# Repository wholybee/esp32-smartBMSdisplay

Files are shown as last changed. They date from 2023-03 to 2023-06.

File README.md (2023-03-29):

# esp32-smartBMSdisplay
ESP32 version of JBD BMS display with Bluetooth connection

This is a BMS monitor for JBD and Overkill Solar BMS. It supports bluetooth connection to the BMS, and can alarm prior to BMS disconnect per ABYC recommendation. It is inspired by a project at https://github.com/vagueDirector/ArduinoXiaoxiangSmartBMSDisplay, but bears little resemblance at this point.

This project uses the Overkill Solar library for accessing the BMS, and modifiyed code from https://github.com/avinabmalla/ESP32_BleSerial

I used an ESP32-WROOM. Others might work also. BLE enabled Arduinos will not work. The ESP32 will connect to the first BMS it finds via bluetooth. Button one cycles through screens, and button two silences the alarm if it is triggered.

To use the alarm requires some changes in the BMS programming. There is a parameter for the delay in seconds before the cutoff occurs. Normally this is set very small, to 1 or 2 seconds. This value is how long of a warning you will get before the cutoff occurs. Some versions of the app do not allow this to be set greater than 10 seconds, but using the Overkill Solar app allows higher values.

Care should be taken when selecting the delay value. If an overvoltage or undervoltage situation occurs, there should be no issue waiting 20 or 30 seconds. If an overcurrent situation occurs, you really should not wait to disconnect to allow for an alarm, regardless of what ABYC says. So, I suggest leaving the delay for overcurrent very low, and changing the delay for overvoltage to 20 or 30 seconds.

ESP32 WROOM - https://www.amazon.com/gp/product/B08MQDS6WV/ref=ppx_yo_dt_b_search_asin_title
128x64 OLED screen - https://www.amazon.com/gp/product/B08BRCBKNR/ref=ppx_yo_dt_b_asin_title_o01_s00
Button - https://www.digikey.com/en/products/detail/c-k/KSA0A531-LFTR/5975610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
Button cap - https://www.digikey.com/en/products/detail/c-k/BTNK0120/498768?s=N4IgTCBcDaICwAYCMBaJYDMBOFA5AIiALoC%2BQA
Buzzer - https://www.amazon.com/gp/product/B07TRK5M2T/ref=ppx_yo_dt_b_search_asin_title

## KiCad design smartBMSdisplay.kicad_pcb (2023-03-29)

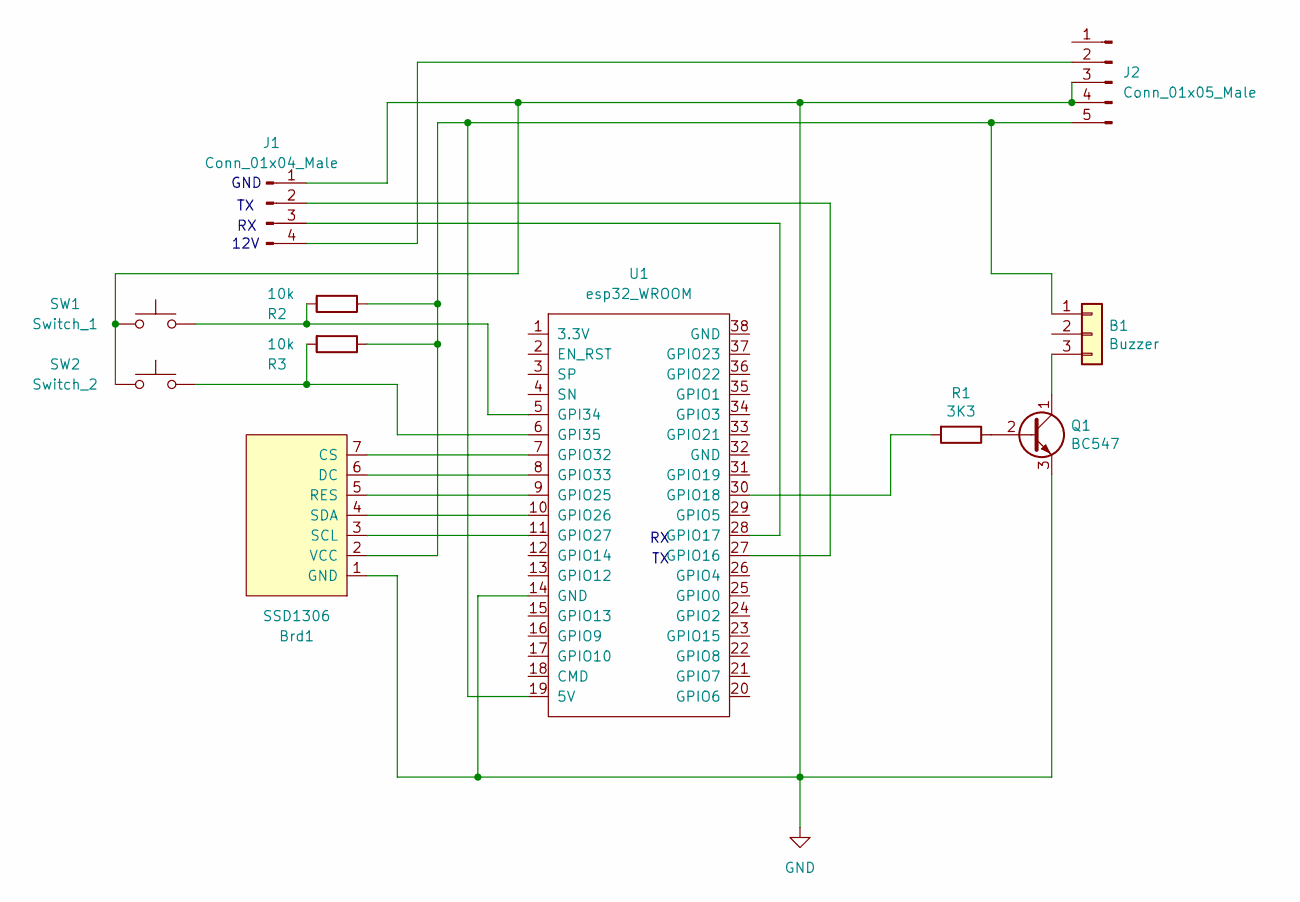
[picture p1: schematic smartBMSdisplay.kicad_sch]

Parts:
B1: Buzzer; PinHeader_1x03_P2.00mm_Vertical
Brd1: SSD1306; 128x64OLED
J1: Conn_01x04_Male; PinHeader_1x04_P2.54mm_Vertical
J2: Conn_01x05_Male; PinHeader_1x05_P2.54mm_Vertical
Q1: BC547; TO-92_HandSolder
R1: 3K3; R_Axial_DIN0207_L6.3mm_D2.5mm_P10.16mm_Horizontal
R2, R3: 10k; R_Axial_DIN0207_L6.3mm_D2.5mm_P10.16mm_Horizontal
SW1: Switch_1; SW_Tactile_Straight_KSA0Axx1LFTR
SW2: Switch_2; SW_Tactile_Straight_KSA0Axx1LFTR
U1: esp32_WROOM; ESP32_Devkit_38Pins

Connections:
GND: Brd1.1 (GND), J1.1, J2.3, J2.4, Q1.3 (E), SW1.2, SW2.2, U1.14 (GND)
unnamed: B1.1, Brd1.2 (VCC), J2.5, R2.1, R3.1, U1.19 (5V)
unnamed: B1.3, Q1.1 (C)
unnamed: Brd1.3 (SCL), U1.11 (GPIO27)
unnamed: Brd1.4 (SDA), U1.10 (GPIO26)
unnamed: Brd1.5 (RES), U1.9 (GPIO25)
unnamed: Brd1.6 (DC), U1.8 (GPIO33)
unnamed: Brd1.7 (CS), U1.7 (GPIO32)
unnamed: J1.2, U1.27 (GPIO16)
unnamed: J1.3, U1.28 (GPIO17)
unnamed: J1.4, J2.2
unnamed: Q1.2 (B), R1.1
unnamed: R1.2, U1.30 (GPIO18)
unnamed: R2.2, SW1.1, U1.5 (GPI34)
unnamed: R3.2, SW2.1, U1.6 (GPI35)

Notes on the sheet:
12V
GND

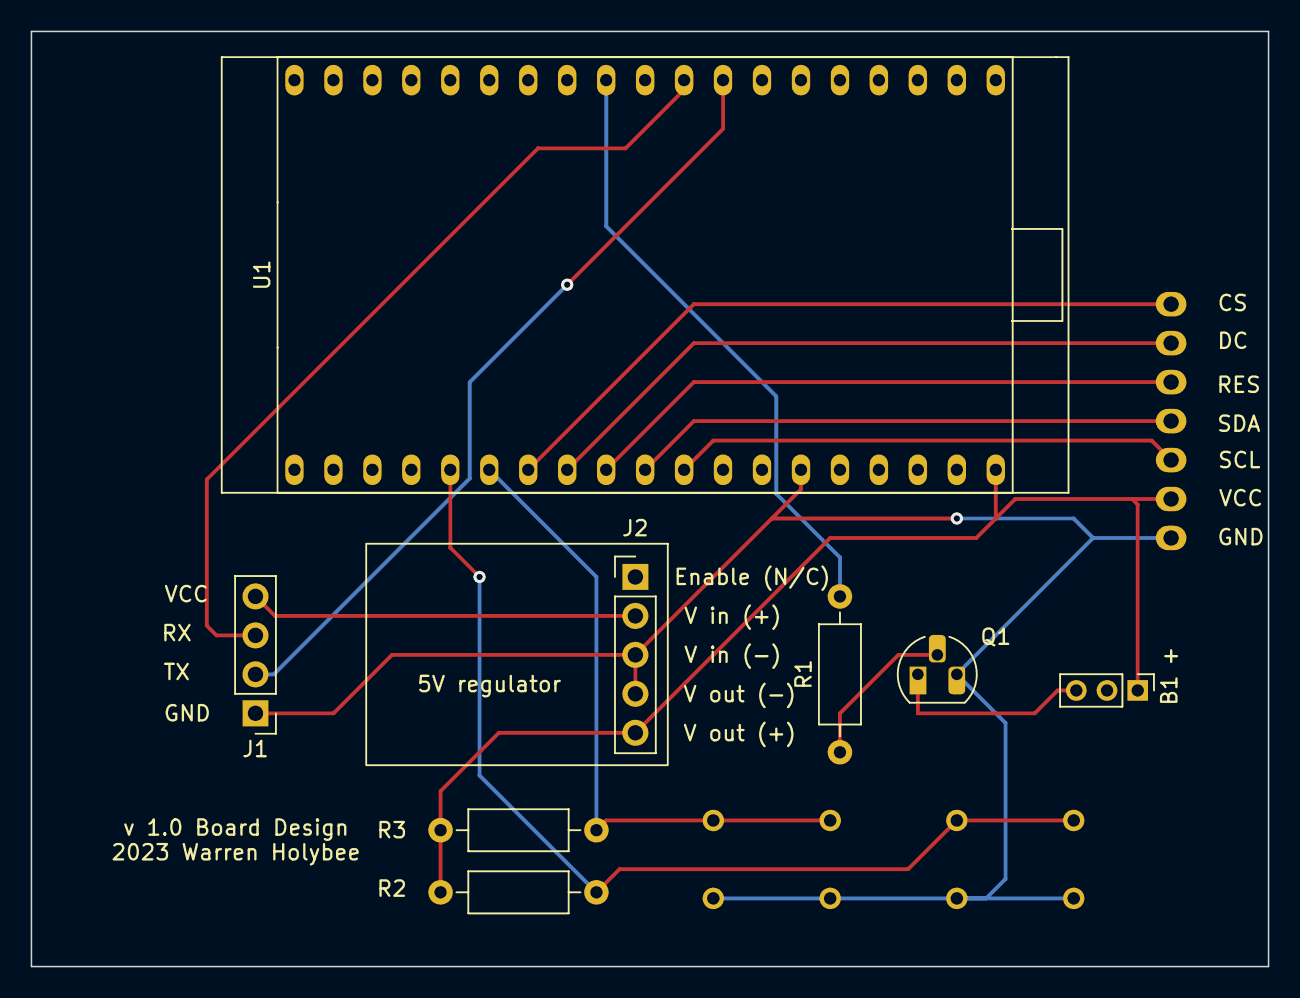
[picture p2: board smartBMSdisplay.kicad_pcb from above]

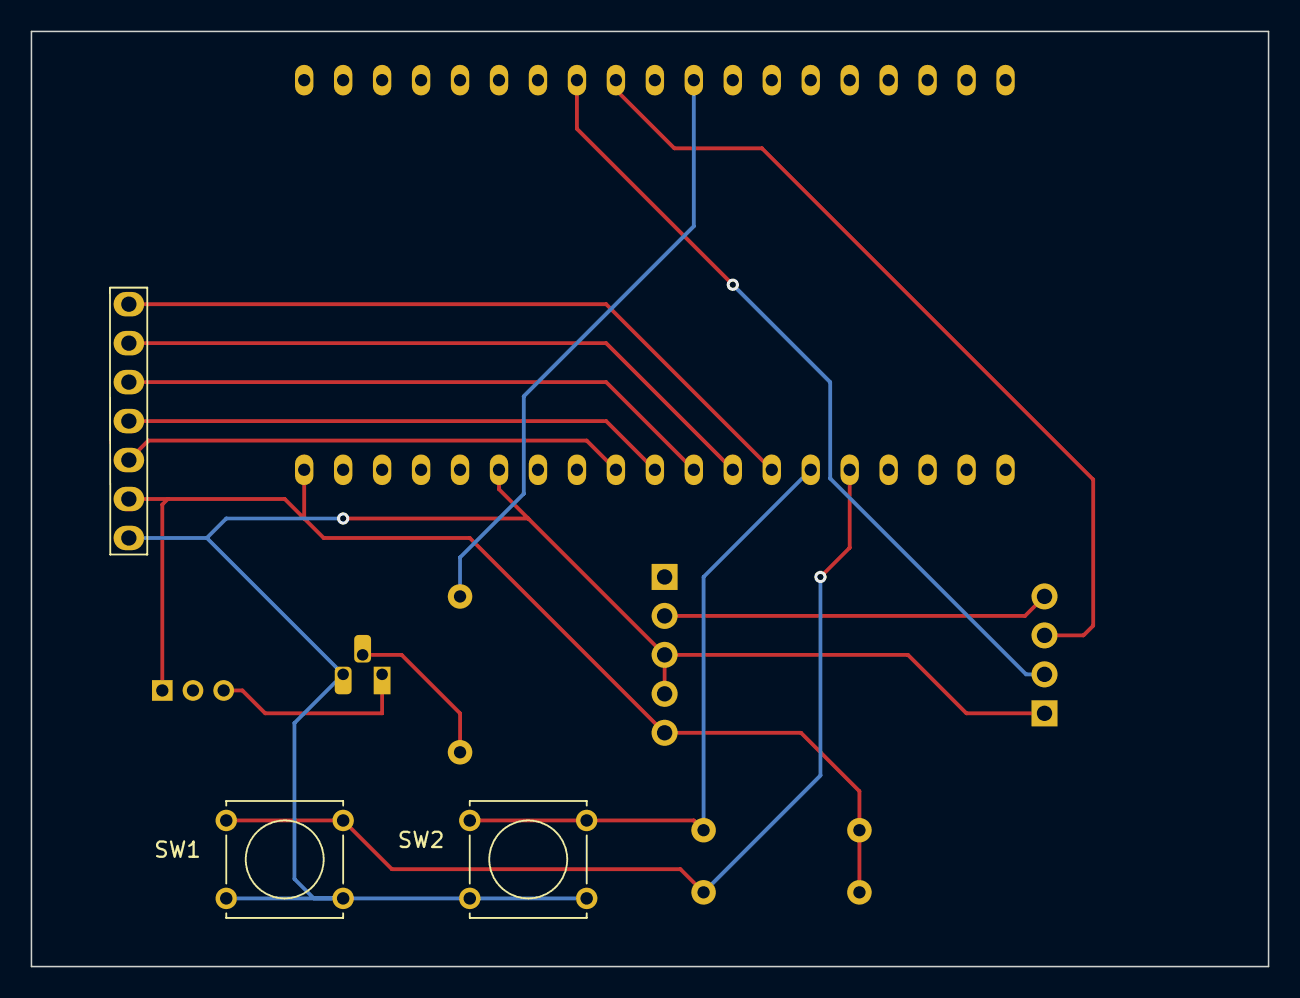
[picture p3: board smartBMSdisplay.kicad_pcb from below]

Board: 2 copper layers, 80.6 x 61.0 mm, 11 parts (3 on the bottom side), 15 nets.

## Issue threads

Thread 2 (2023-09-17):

is there a wiring diagram for your code please? I am looking at trying to read from two jbd BMS and display combined soc. information... thanks

CornishWoodsman, 2023-09-17:

wholybee, 2023-09-19:
The Kicad files include a schematic and PCB design files. This project can only talk to one BMS at a time.  To talk to 2 would be much easier with a wired connection instead of bluetooth.

CornishWoodsman, 2023-09-24:
My battery boxes are sealed and I have no access to the wired connection.
I have successfully read them consecutively from my linux box. Wondered if you set the MAC addresses that would be possible?
Thanks- I'll have a look atthe Kicad files- I admit I hadn't thought of looking at them! :-)

wholybee, 2023-09-24:
As is, the code connects to the first BMS is finds. You could pretty easily change that to connect to a BMS with a specific name. However, it would be difficult to make it connect to both BMS's at the same time. The easiest solution is to just build 2 of them.  SOC should be the same on 2 BMS of 2 batteries connected together in either series or parallel.  So you only really need SOC from one of them, and then cell information from all the cells.

CornishWoodsman, 2023-10-28:
So I finally have this working as you intended.
I do not need both connected at the same time, rather in sequence...
First one, then the other and looping that way...

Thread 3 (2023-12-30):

Guru Meditation Error: Core  0 panic'ed (Unhandled debug exception)

softwarecrash, 2023-12-30:
Hello,
i stuck a little bit with your project,
my bms have a little different serviceUUID not ff00 but fff0 so i changed it in BleSerialClient.h, now the device is discovered.
but when it try to connect the esp crashes with follow ecexption.

when i put in the field the full ServiceUUID it doenst crash and see the device but never try to connect to

```
00:23:25.606 > BLE Advertised Device found: Name: , Address: 10:2b:41:96:4f:e2, manufacturer data: 7500420401207e210f0022014101010001000000000000000008
00:23:26.782 > BLE Advertised Device found: Name: C8C9A3C72416, Address: c8:c9:a3:c7:24:16, serviceUUID: 0000fff0-0000-1000-8000-00805f9b34fb, serviceUUID: 0000fff0-0000-1000-8000-00805f9b34fb, txPower: 3
00:23:26.799 > [  3452][I][BleSerialClient.cpp:73] connectToServer(): Forming a connection to
00:23:26.806 > c8:c9:a3:c7:24:16
00:23:26.808 > [  3464][I][BleSerialClient.cpp:79] connectToServer():  - Created client
00:23:26.814 > [  3464][I][BLEDevice.cpp:622] addPeerDevice(): add conn_id: 0, GATT role: client
00:23:26.870 > [  3529][I][BleSerialClient.cpp:55] onConnect(): In onConnect()
00:23:26.877 > [  3530][I][BleSerialClient.cpp:85] connectToServer():  - Connected to server
00:23:26.925 > Guru Meditation Error: Core  0 panic'ed (Unhandled debug exception).
00:23:26.932 > Debug exception reason: Stack canary watchpoint triggered (BTU_TASK)
00:23:26.938 > Core  0 register dump:
00:23:26.940 > PC      : 0x40094cf3  PS      : 0x00060136  A0      : 0x80096620  A1      : 0x3ffd0ab0
00:23:26.984 > ₉₂₄₃ [33m=> 0x40094cf3: compare_and_set_native at /home/runner/work/esp32-arduino-lib-builder/esp32-arduino-lib-builder/esp-idf/components/esp_hw_support/include/soc/compare_set.h:25
00:23:26.984 >       (inlined by) spinlock_acquire at /home/runner/work/esp32-arduino-lib-builder/esp32-arduino-lib-builder/esp-idf/components/esp_hw_support/include/soc/spinlock.h:103
00:23:26.984 >       (inlined by) xPortEnterCriticalTimeout at /home/runner/work/esp32-arduino-lib-builder/esp32-arduino-lib-builder/esp-idf/components/freertos/port/xtensa/port.c:288₉₂₄₃ [0m
00:23:26.985 > A2      : 0x3ffb6c34  A3      : 0xb33fffff  A4      : 0x0000abab  A5      : 0x0000cdcd
00:23:26.985 > A6      : 0x00060123  A7      : 0x00060123  A8      : 0x0000cdcd  A9      : 0xffffffff
00:23:26.985 > A10     : 0x00000008  A11     : 0x00000001  A12     : 0x00000005  A13     : 0x00000008
00:23:26.985 > A14     : 0x003fffff  A15     : 0x00000000  SAR     : 0x0000001b  EXCCAUSE: 0x00000001
00:23:26.985 > EXCVADDR: 0x00000000  LBEG    : 0x40090518  LEND    : 0x4009052e  LCOUNT  : 0x00000000
```

any idea how to solve this crash?
thank you

Closed 2023-12-31.

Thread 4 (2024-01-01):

BLESerialClient class modifaction

softwarecrash, 2024-01-01:
hello,
your modification of the BLESerial to BLESerielClient is exact what is searched for.
but i need to switch to NIMBLEDevice for save resources.
so i try to modify it but struggle with serveral compiler issues, like virtual class errors.
can you point me the right direction to do that?

another little issue in this class is that the read function never return a -1 like the arduino class, do you have a short idea to fix that?

wholybee, 2024-01-01:
I'm sorry but I haven't looked at this code in a long time. I did struggle with it because the BLE protocol isn't intended for serial communications like the BMS uses. It really should be regular BT but that isn't what the JBD BMS uses.  I never was able to get Arduino to communicate over BLE with the BMS. The Arduino BLE library works in a very different way.
I don't know what NIMBLEDevice is.
I do not believe it is possible to connect to more than one server.
To connect to a specific device look in
BleSerialClient::onResult(BLEAdvertisedDevice advertisedDevice)
and add code to check that the advertised device is the one you wish to connect to.

softwarecrash, 2024-01-01:
Thanks for your quick answer.

NIMble is a fork of the arduino ble library but with signifikant smaler memory Impact, and i need so i got out of memory.

So when No multiple Connection is possibile i think a Connect-read-disconnect and select the next device will work too.
So im relative new to the Bluetooth world, its Not my recommend Thing to use, but the Project need it.

With Cour serialclient Class i got a succsessfull Connection to my device and get communication, so its nearly perfect. But struggle to rewrite it to NIMble.
You can Take a Look at my try
https://github.com/softwarecrash/nimble-serial
Something is wrong with the class constructor when it use NIMble insgesamt of ble and the Compiler tells me that virtual Abstract class Not usable.

I Hope you have a little Bit time to Help me out of this.

Thank you

wholybee, 2024-01-02:
I don't think you are going to get the SerialBLE library to work with the Arduino library, or at least I couldn't.  It is a very different implementation. The ESP32 library uses callbacks for when data arrives, while the Arduino loops checking for data. No matter what I did, the Arduino library was losing data after 20 bytes or so. BLE is meant for just updating data points, like a weather station would just update windspeed and direction. The Arduino library is fine for that because it is only a few bytes. And the BMS uses BLE, so that is what I had to use. But the Arduino library just didn't work with the BMS.
If you have a choice, I would select BT, not BLE. BT would allow connection to multiple devices, I think. And BT is much simpler than BLE and supports serial natively.  The disconnect/reconnect idea might take about 5 seconds. Another option would be to have a second Bluetooth chip, or even a whole another esp32.
If you are running out of memory, can you use a different model esp32 with more?

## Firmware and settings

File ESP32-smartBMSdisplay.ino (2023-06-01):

#include <bms2.h>
#include <SoftwareSerial.h> // Second serial port for connecting to the BMS
#include <U8g2lib.h> // Needed for the display
#include <SPI.h> // Needed for the display
#include "BleSerialClient.h"
#include "ESP32-smartBMSdisplay.h"
// define DEBUG true

void setup() {
#ifdef DEBUG
Serial.println(F("BMS Monitor Init"));
#endif

Serial.begin(115200);

if (haveBT) {
  startBluetooth();
   
  } else {
  MySoftwareSerial.begin(9600);
  }

pinMode(ALARM_PIN, OUTPUT);
pinMode(SW1, INPUT);
pinMode(SW2, INPUT);
digitalWrite(ALARM_PIN, LOW);
u8g2.begin(); 
u8g2.setContrast(1); // 0-255 display brightness
#ifdef DEBUG
Serial.println(F("Init Complete."));
#endif

}

void loop() { 
bms.begin(&MySerial);
if (haveBT) {
    while (!SerialBT.connected()) SerialBT.bleLoop();
}
  for(int i=0;i<3;i++){
    checkProtectionParms();
    bms.main_task(true);
    myNumCells = bms.get_num_cells();
    delay(100);
   }
#ifdef DEBUG    
    Serial.print(F("Number of Cells:"));
    Serial.println(myNumCells);
#endif

    while (SerialBT.connected() || !haveBT){
            bms.main_task(true);
            updateBasic();      // Pack Voltage, Current, SOC, etc.
            updateCells();      // Cell volages and Balancer status
            updateStatus();     // Protection information
            setMyAlarm ();        // Do we need to sound MyAlarm of pending protection?
            buzzer();            
            updateDisplay();
            if (haveBT==true) SerialBT.bleLoop();
              if (digitalRead(SW2)) depressed = false;
              if (!digitalRead(SW2) & !depressed) {
                    depressed = true;
                    pagenumber++;
                    if (pagenumber==END) pagenumber = 0;
                   // timestamp_100ms = millis();
                      
                
              }
    }

    MyAlarm = false;
    digitalWrite (ALARM_PIN, false);
    bms.end();
            
}



void startBluetooth() {
  // Get unit MAC address
  esp_read_mac(unitMACAddress, ESP_MAC_WIFI_STA);
  
  // Convert MAC address to Bluetooth MAC (add 2): https://docs.espressif.com/projects/esp-idf/en/latest/esp32/api-reference/system/system.html#mac-address
  unitMACAddress[5] += 2;                                                          
  
  //Create device name
  sprintf(deviceName, "BMSMonitor-%02X%02X", unitMACAddress[4], unitMACAddress[5]); 

  //Init BLE Serial
  SerialBT.begin(deviceName);
  SerialBT.setTimeout(10);
}

void setMyAlarm (void) {
  if (PackVoltagef > povt-0.1) { 
      MyAlarm = true; 
      packOver = true;
      #ifdef DEBUG
      Serial.println ("Pack Overvoltage!");
      #endif
      }
  else if (PackVoltagef < puvt+0.1) { 
      MyAlarm = true; 
      PackUnder = true;
      #ifdef DEBUG
      Serial.println ("Pack Undervoltage!");
      #endif
      }
  else if (PackCurrentf > coct) { 
      MyAlarm = true; 
      chargeOvercurrent = true;
      #ifdef DEBUG
      Serial.println ("Pack overcurrent!");
      #endif
      }
  else if (PackCurrentf < doct*(-1)) { 
      MyAlarm = true; 
      dischargeOvercurrent = true;
      #ifdef DEBUG
      Serial.println ("Pack Discharge Overcurrent!");
      #endif
      }
  else if (setCellMyAlarm()) { 
      MyAlarm = true; 
      #ifdef DEBUG
      Serial.println ("Cell Voltage Alarm!");
      #endif
      }
  else MyAlarm = false;
  
}

bool setCellMyAlarm (void) {
  bool ca = false;
  for (int c = 0;c < myNumCells;c++){
            if (myCellVoltages[c]>covt) {
              ca = true;
              cellOver = true;
            }
            if (myCellVoltages[c]<cuvt) {
              ca = true;
              cellUnder = true;
            }
  }
  return ca;
}

void buzzer (void) {
  
  if (MyAlarm == true) {
    if (!digitalRead (SW1)) mute = true; 
    Serial.println("Alarm.");
    if (millis() - buzzerTimestamp >= 100) {    
      if (mute) { 
        myBeep = LOW; 
      } else { 
        myBeep = !myBeep;
      }
#ifdef DEBUG
      if (myBeep)  Serial.println("Beep.");
#endif
      digitalWrite (ALARM_PIN, myBeep);
      buzzerTimestamp = millis();
    }    
  } else {
#ifdef DEBUG
    Serial.println("No Alarm.");
#endif
    digitalWrite (ALARM_PIN, LOW);
    mute = false;
  }  
}



void checkProtectionParms (void) {
povt = bms.get_0x20_batt_over_volt_trig() / 1000.0;
puvt = bms.get_0x22_batt_under_volt_trig() / 1000.0;
covt = bms.get_0x24_cell_over_volt_trig() / 1000.0;
cuvt = bms.get_0x26_cell_under_volt_trig() / 1000.0;
coct = bms.get_0x28_charge_over_current_trig() / 1000.0;
doct = bms.get_0x29_discharge_over_current_release() / 1000.0;
#ifdef DEBUG  
  Serial.print("Pack Overvoltage:");
  Serial.println(povt);

  Serial.print("Pack Undervoltage:");
  Serial.println(puvt);

  Serial.print("Cell Overvoltage:");
  Serial.println(covt);

  Serial.print("Cell Undervoltage:");
  Serial.println(cuvt);

  Serial.print("Charge Overcurrent:");
  Serial.println(coct);

  Serial.print("Discharge Overcurrent:");
  Serial.println(doct);
#endif
}


void updateCells (void) {
    CellMax = 0.0;
    CellMin = 5.0;
    Cellavg = 0.0;
    for (int c = 0;c < myNumCells;c++){
      if (bms.get_cell_voltage(c) != 0) {
        myCellVoltages[c]=bms.get_cell_voltage(c);
        balancerStates[c]=bms.get_balance_status(c);
        if (myCellVoltages[c] > CellMax ) CellMax = myCellVoltages[c];
        if (myCellVoltages[c] < CellMin ) CellMin = myCellVoltages[c];
        Cellavg += myCellVoltages[c];
    }
    Cellavg = Cellavg / myNumCells;
    Celldiff = CellMax - CellMin;
#ifdef DEBUG
    Serial.print("    Cell:");
    Serial.print(c+1);
    Serial.print(" ");
    Serial.print(myCellVoltages[c]);
    Serial.print(balancerStates[c]?'*':' ');
#endif
  }
#ifdef DEBUG
  Serial.println();
#endif

}



void updateBasic (void) {
            // bms.query_0x03_basic_info();
            PackVoltagef = bms.get_voltage();
            PackCurrentf = bms.get_current();
            RSOC = bms.get_state_of_charge();
            RemainCapacityf = bms.get_balance_capacity();
            Temp_probe_1f = bms.get_ntc_temperature(1);

}


void updateStatus (void) {
  // Mosfets
  chargeFet = bms.get_charge_mosfet_status();
  dischargeFet = bms.get_discharge_mosfet_status();

#ifdef DEBUG
  Serial.print(F("Mosfet Charge = "));
  Serial.print(chargeFet);
  Serial.print(F("  Mosfet DisCharge = "));
  Serial.println(dischargeFet);
#endif

  // Pack Protection states
  prot_status = bms.get_protection_status();
  cellOver = prot_status.single_cell_overvoltage_protection; 
  cellUnder = prot_status.single_cell_undervoltage_protection; 
  packOver = prot_status.whole_pack_overvoltage_protection;
  PackUnder = prot_status.whole_pack_undervoltage_protection;
  chargeOverTemp = prot_status.charging_over_temperature_protection;
  chargeUnderTemp = prot_status.discharge_low_temperature_protection;
  dischargeOverTemp = prot_status.discharge_over_temperature_protection;
  dischargeUnderTemp = prot_status.discharge_low_temperature_protection;
  chargeOvercurrent = prot_status.charging_overcurrent_protection;
  dischargeOvercurrent = prot_status.discharge_overcurrent_protection;
  shortCircuit = prot_status.short_circuit_protection;
  AFEerror = prot_status.front_end_detection_ic_error;

#ifdef DEBUG
  if(AFEerror) Serial.println(F("AFE ERROR"));
  else if(shortCircuit) Serial.println(F("SHORT CIRCUIT"));
  else if(cellOver) Serial.println(F("Cell Overvoltage"));
  else if(cellUnder) Serial.println(F("Cell Undervoltage"));
  else if(packOver) Serial.println(F("Pack Overvoltage"));
  else if(PackUnder) Serial.println(F("Pack Undervoltage"));
  else if(chargeOverTemp) Serial.println(F("Charge Overtemp"));
  else if(chargeUnderTemp) Serial.println(F("Charge Undertemp"));
  else if(dischargeOverTemp) Serial.println(F("Discharge Overtemp"));
  else if(dischargeUnderTemp) Serial.println(F("Discharge Undertemp"));
  else if(chargeOvercurrent) Serial.println(F("Charge Overcurrent"));
  else if(dischargeOvercurrent) Serial.println(F("Discharge Overcurrent"));
  else if(PackCurrentf>0) Serial.println(F("Charging"));
  else if(PackCurrentf<0) Serial.println(F("Discharging"));
  else if(PackCurrentf==0) Serial.println(F("Idle"));
#endif  


}

void updateDisplay(void){

  switch (pagenumber) {
    case SUMMARY:
      displaySummary();
      break;

    case SOC:
      displaySOC();
      break;
    
    case VOLTAGE:
      displayVoltage();
      break;

    case AMPS:
      displayCurrent();
      break;

    case CELLS:
      displayCells();
      break;
  }

}

void displaySOC (void) {
u8g2.firstPage();
  do {
 
    //SOC Meter
  u8g2.setFont(u8g2_font_inr24_mf);  
  u8g2.setCursor(2, 32);
  float stateOfCharge = RSOC;
  u8g2.print(stateOfCharge,0);
  u8g2.print("%");
  u8g2.setFont(u8g2_font_7x13_mf); 
  u8g2.setCursor(2, 52);
  u8g2.print(RemainCapacityf,0);
  u8g2.print("Ah");
  u8g2.setCursor(65, 52);
  u8g2.print(RemainCapacityf*12.9,0);
  u8g2.print("Wh");

    //Pack status
  u8g2.setFont(u8g2_font_5x8_mf); // choose font 
  u8g2.setCursor(1, 63);
  if(AFEerror) u8g2.print(F("AFE ERROR"));
  else if(shortCircuit) u8g2.print(F("SHORT CIRCUIT"));
  else if(cellOver) u8g2.print(F("Cell Overvoltage"));
  else if(cellUnder) u8g2.print(F("Cell Undervoltage"));
  else if(packOver) u8g2.print(F("Pack Overvoltage"));
  else if(PackUnder) u8g2.print(F("Pack Undervoltage"));
  else if(chargeOverTemp) u8g2.print(F("Charge Overtemp"));
  else if(chargeUnderTemp) u8g2.print(F("Charge Undertemp"));
  else if(dischargeOverTemp) u8g2.print(F("Discharge Overtemp"));
  else if(dischargeUnderTemp) u8g2.print(F("Discharge Undertemp"));
  else if(chargeOvercurrent) u8g2.print(F("Charge Overcurrent"));
  else if(dischargeOvercurrent) u8g2.print(F("Discharge Overcurrent"));
  else if(PackCurrentf>0) u8g2.print(F("Charging"));
  else if(PackCurrentf<0) u8g2.print(F("Discharging"));
  else if(PackCurrentf==0) u8g2.print(F("Idle"));
} while (u8g2.nextPage());

}

void displayVoltage (void) {
u8g2.firstPage();
  do {
 
    //Volt Meter
  u8g2.setFont(u8g2_font_inr24_mf);   //  u8g2_font_fub30_tr
  u8g2.setCursor(1, 32);
  u8g2.print(PackVoltagef,2);
  u8g2.print("V");
  u8g2.setFont(u8g2_font_7x13_mf); 
  u8g2.setCursor(2, 52);
  u8g2.print(PackCurrentf,0);
  u8g2.print("A");
  u8g2.setCursor(62, 52);
  u8g2.print(PackCurrentf*PackVoltagef,0);
  u8g2.print("W");

    //Pack status
  u8g2.setFont(u8g2_font_5x8_mf); // choose font 
  u8g2.setCursor(1, 63);
  if(AFEerror) u8g2.print(F("AFE ERROR"));
  else if(shortCircuit) u8g2.print(F("SHORT CIRCUIT"));
  else if(cellOver) u8g2.print(F("Cell Overvoltage"));
  else if(cellUnder) u8g2.print(F("Cell Undervoltage"));
  else if(packOver) u8g2.print(F("Pack Overvoltage"));
  else if(PackUnder) u8g2.print(F("Pack Undervoltage"));
  else if(chargeOverTemp) u8g2.print(F("Charge Overtemp"));
  else if(chargeUnderTemp) u8g2.print(F("Charge Undertemp"));
  else if(dischargeOverTemp) u8g2.print(F("Discharge Overtemp"));
  else if(dischargeUnderTemp) u8g2.print(F("Discharge Undertemp"));
  else if(chargeOvercurrent) u8g2.print(F("Charge Overcurrent"));
  else if(dischargeOvercurrent) u8g2.print(F("Discharge Overcurrent"));
  else if(PackCurrentf>0) u8g2.print(F("Charging"));
  else if(PackCurrentf<0) u8g2.print(F("Discharging"));
  else if(PackCurrentf==0) u8g2.print(F("Idle"));
} while (u8g2.nextPage());

}


void displayCurrent (void) {
u8g2.firstPage();
  do {
 
    //Amp Meter
  u8g2.setFont(u8g2_font_inr24_mf);  
  u8g2.setCursor(2, 32);
  u8g2.print(PackCurrentf,1);
  u8g2.print("A");
  u8g2.setFont(u8g2_font_7x13_mf); 
  u8g2.setCursor(2, 52);
  u8g2.print(PackVoltagef,2);
  u8g2.print("V");
  u8g2.setCursor(62, 52);
  u8g2.print(PackCurrentf*PackVoltagef,0);
  u8g2.print("W");

    //Pack status
  u8g2.setFont(u8g2_font_5x8_mf); // choose font 
  u8g2.setCursor(1, 63);
  if(AFEerror) u8g2.print(F("AFE ERROR"));
  else if(shortCircuit) u8g2.print(F("SHORT CIRCUIT"));
  else if(cellOver) u8g2.print(F("Cell Overvoltage"));
  else if(cellUnder) u8g2.print(F("Cell Undervoltage"));
  else if(packOver) u8g2.print(F("Pack Overvoltage"));
  else if(PackUnder) u8g2.print(F("Pack Undervoltage"));
  else if(chargeOverTemp) u8g2.print(F("Charge Overtemp"));
  else if(chargeUnderTemp) u8g2.print(F("Charge Undertemp"));
  else if(dischargeOverTemp) u8g2.print(F("Discharge Overtemp"));
  else if(dischargeUnderTemp) u8g2.print(F("Discharge Undertemp"));
  else if(chargeOvercurrent) u8g2.print(F("Charge Overcurrent"));
  else if(dischargeOvercurrent) u8g2.print(F("Discharge Overcurrent"));
  else if(PackCurrentf>0) u8g2.print(F("Charging"));
  else if(PackCurrentf<0) u8g2.print(F("Discharging"));
  else if(PackCurrentf==0) u8g2.print(F("Idle"));
} while (u8g2.nextPage());

}

void displayCells (void) {

u8g2.firstPage();
  do {

  //Cell States
  u8g2.setFont(u8g2_font_7x13_mf); // u8g2.setFont(u8g2_font_9x15_mf);
  u8g2.setCursor(1, 12);
  u8g2.print(myCellVoltages[0],3);
  u8g2.print("v");
  if(balancerStates[0]==1) u8g2.print("*");
  u8g2.setCursor(1, 24);
  u8g2.print(myCellVoltages[1],3);
  u8g2.print("v");
  if(balancerStates[1]==1) u8g2.print("*");

  
  u8g2.setCursor(1, 36);
  u8g2.print(myCellVoltages[2],3);
  u8g2.print("v");
  if(balancerStates[2]==1) u8g2.print("*");
  u8g2.setCursor(1, 48);
  u8g2.print(myCellVoltages[3],3);
  u8g2.print("v");
  if(balancerStates[3]==1) u8g2.print("*");



// Min,Max,Delta

  
  u8g2.setFont(u8g2_font_7x13_mf);
  u8g2.setCursor(62, 12);
  u8g2.print(CellMin,3); u8g2.print("min");
  u8g2.setCursor(62, 24);
  u8g2.print(CellMax,3); u8g2.print("max");
  u8g2.setCursor(62, 36);
  u8g2.print(Celldiff,3); u8g2.print("diff");
  u8g2.drawFrame(58,0,67,39); // u8g2.drawLine(61, 0, 61, 39);

  //Pack status
  u8g2.setFont(u8g2_font_5x8_mf); // choose font 
  u8g2.setCursor(1, 63);
  if(AFEerror) u8g2.print(F("AFE ERROR"));
  else if(shortCircuit) u8g2.print(F("SHORT CIRCUIT"));
  else if(cellOver) u8g2.print(F("Cell Overvoltage"));
  else if(cellUnder) u8g2.print(F("Cell Undervoltage"));
  else if(packOver) u8g2.print(F("Pack Overvoltage"));
  else if(PackUnder) u8g2.print(F("Pack Undervoltage"));
  else if(chargeOverTemp) u8g2.print(F("Charge Overtemp"));
  else if(chargeUnderTemp) u8g2.print(F("Charge Undertemp"));
  else if(dischargeOverTemp) u8g2.print(F("Discharge Overtemp"));
  else if(dischargeUnderTemp) u8g2.print(F("Discharge Undertemp"));
  else if(chargeOvercurrent) u8g2.print(F("Charge Overcurrent"));
  else if(dischargeOvercurrent) u8g2.print(F("Discharge Overcurrent"));
  else if(PackCurrentf>0) u8g2.print(F("Charging"));
  else if(PackCurrentf<0) u8g2.print(F("Discharging"));
  else if(PackCurrentf==0) u8g2.print(F("Idle"));

 // Mosfet Status
  u8g2.setFont(u8g2_font_5x8_mf);
  u8g2.setCursor(97, 55);
  u8g2.print("C:");
  if(chargeFet)u8g2.print("ON");
  else u8g2.print("OFF");
  u8g2.setCursor(97, 63); 
  u8g2.print("D:");
  if(dischargeFet)u8g2.print("ON");
  else u8g2.print("OFF");

} while (u8g2.nextPage());


}


void displaySummary (void) {

u8g2.firstPage();
  do {

  // Power Meter
  u8g2.drawFrame(0,0,58,39);
  u8g2.setFont(u8g2_font_7x13_mf); // choose font 
  u8g2.setCursor(3, 12);
  u8g2.print(PackVoltagef,2);
  u8g2.setCursor(49, 12);
  u8g2.print("V");
  u8g2.setCursor(3, 24);
  u8g2.print(PackCurrentf,1);
  u8g2.setCursor(49, 24);
  u8g2.print("A");
  u8g2.setCursor(3, 36);
  u8g2.print(PackVoltagef *PackCurrentf,1);
  u8g2.setCursor(49, 36);
  u8g2.print("W");

  //SOC Meter
  u8g2.setCursor(67, 12);
  float stateOfCharge = RSOC;
  u8g2.print(stateOfCharge,0);
  u8g2.print("%");
  u8g2.setCursor(67, 24);
  u8g2.print(RemainCapacityf,0);
  u8g2.print("Ah");
  u8g2.setCursor(67, 36);
  u8g2.print(Temp_probe_1f,1);
  u8g2.print("c");

  //Pack status
  u8g2.setFont(u8g2_font_5x8_mf); // choose font 
  u8g2.setCursor(2, 47);
  if(AFEerror) u8g2.print(F("AFE ERROR"));
  else if(shortCircuit) u8g2.print(F("SHORT CIRCUIT"));
  else if(cellOver) u8g2.print(F("Cell Overvoltage"));
  else if(cellUnder) u8g2.print(F("Cell Undervoltage"));
  else if(packOver) u8g2.print(F("Pack Overvoltage"));
  else if(PackUnder) u8g2.print(F("Pack Undervoltage"));
  else if(chargeOverTemp) u8g2.print(F("Charge Overtemp"));
  else if(chargeUnderTemp) u8g2.print(F("Charge Undertemp"));
  else if(dischargeOverTemp) u8g2.print(F("Discharge Overtemp"));
  else if(dischargeUnderTemp) u8g2.print(F("Discharge Undertemp"));
  else if(chargeOvercurrent) u8g2.print(F("Charge Overcurrent"));
  else if(dischargeOvercurrent) u8g2.print(F("Discharge Overcurrent"));
  else if(PackCurrentf>0) u8g2.print(F("Charging"));
  else if(PackCurrentf<0) u8g2.print(F("Discharging"));
  else if(PackCurrentf==0) u8g2.print(F("Idle"));

  //Cell and MOSFET States
  u8g2.setCursor(2, 55);
  u8g2.print(myCellVoltages[0],3);
  u8g2.print("v");
  if(balancerStates[0]==1) u8g2.print("*");
  u8g2.setCursor(40, 55);
  u8g2.print(myCellVoltages[1],3);
  u8g2.print("v");
  if(balancerStates[1]==1) u8g2.print("*");
  u8g2.setCursor(97, 55);
  u8g2.print("C:");
  if(chargeFet)u8g2.print("ON");
  else u8g2.print("OFF");
  
  u8g2.setCursor(2, 63);
  u8g2.print(myCellVoltages[2],3);
  u8g2.print("v");
  if(balancerStates[2]==1) u8g2.print("*");
  u8g2.setCursor(40, 63);
  u8g2.print(myCellVoltages[3],3);
  u8g2.print("v");
  if(balancerStates[3]==1) u8g2.print("*");
  u8g2.setCursor(97, 63);
  u8g2.print("D:");
  if(dischargeFet)u8g2.print("ON");
  else u8g2.print("OFF");
  
  } while (u8g2.nextPage());


}

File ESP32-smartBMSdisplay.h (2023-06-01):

//#define MySerial MySoftwareSerial
#define MySerial SerialBT
static bool haveBT = true;

#define SW1 35
#define SW2 34
#define ALARM_PIN 18
#define SCL 27
#define SDA 26
#define RST 25
#define DC 33
#define CS 32

#define RX 25
#define TX 27

// display pages
int pagenumber = 0;

#define SUMMARY 0
#define SOC 1
#define VOLTAGE 2
#define AMPS 3
#define CELLS 4
#define END 5


static BleSerialClient SerialBT;
uint8_t unitMACAddress[6];  // Use MAC address in BT broadcast and display
char deviceName[20];        // The serial string that is broadcast.

uint32_t timestamp_100ms = 0;
uint32_t buzzerTimestamp = 0;

float povt = 15.0;    // pack over voltage trigger
float puvt = 9.6;   // pack under voltage trigger
float covt = 3.750;  // cell over voltage trigger
float cuvt = 2.4;   // cell under voltage trigger
float coct = 120.0;   // charge over current trigger
float doct = 120.0;   // discharge over current trigger
bool MyAlarm = false;
bool myBeep = false;
bool mute = false;
bool depressed = false;

// Global battery stat variables (For printing to displays)
float CellMin = 5.0; // Default value > max possible cell votlage
float CellMax = 0.0;
float Cellavg = 0.0; 
float Celldiff=0.0;
float myCellVoltages[8] = {0,0,0,0,0,0,0,0};
int balancerStates[8] = {0,0,0,0,0,0,0,0};
int myNumCells = 0;
float PackVoltagef = 0.0;
float PackCurrentf = 0.0;
float RemainCapacityf = 0.0;
int RSOC = 0;
float Temp_probe_1f = 0.0;
float Temp_probe_2f = 0.0;
bool chargeFet = false;
bool dischargeFet = false;
bool cellOver = false;
bool cellUnder = false;
bool packOver = false;
bool PackUnder = false;
bool chargeOverTemp = false;
bool chargeUnderTemp = false;
bool dischargeOverTemp = false;
bool dischargeUnderTemp = false;
bool chargeOvercurrent = false;
bool dischargeOvercurrent = false;
bool shortCircuit = false;
bool AFEerror = false;


// objects we need

SoftwareSerial MySoftwareSerial(RX, TX);
U8G2_SSD1309_128X64_NONAME2_1_4W_SW_SPI u8g2( U8G2_R0, SCL , SDA  , CS , DC , RST );
OverkillSolarBms2 bms;
ProtectionStatus prot_status;

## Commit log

2023-03-08 First working bluetooth version
    [smartBMSdisplay.kicad_pcb, smartBMSdisplay.kicad_sch]
2023-03-29 Update Readme, misc display changes, update PCB
    [smartBMSdisplay.kicad_pcb, smartBMSdisplay.kicad_sch]
